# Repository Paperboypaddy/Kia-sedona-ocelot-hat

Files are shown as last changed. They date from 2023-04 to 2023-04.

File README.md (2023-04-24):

# Kia Sedona 2004 Ocelot Hat
The idea of this Ocelot V2 Hat design is to control the stock cruise control system in the car currently as well as adding a K Line Lin Bus tranciever to act like a ELM327 to capture car speed and other stats for openpilot.

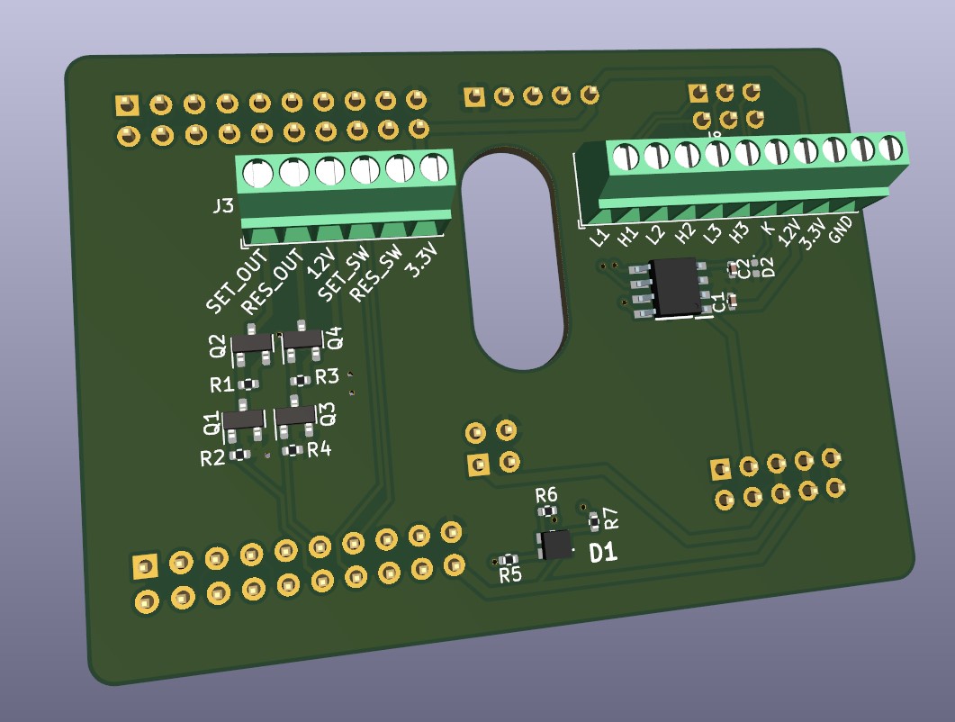
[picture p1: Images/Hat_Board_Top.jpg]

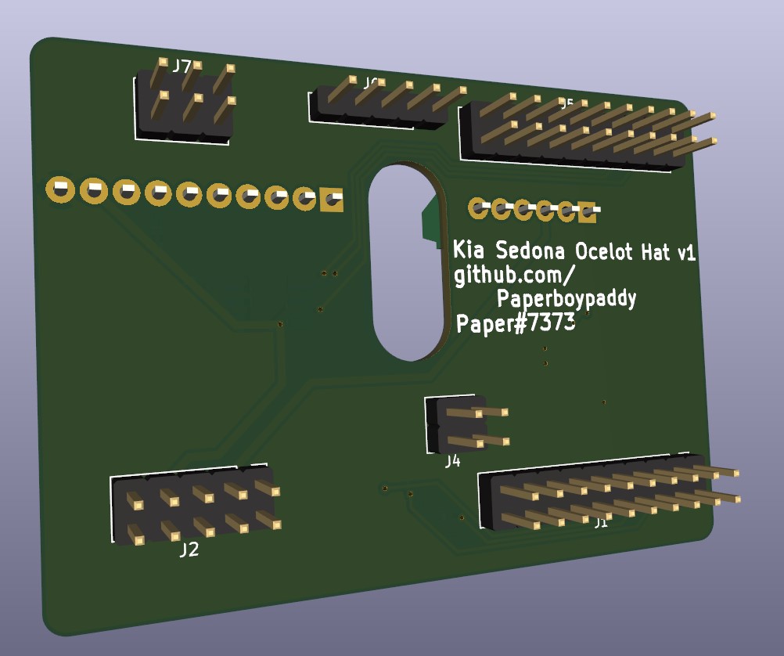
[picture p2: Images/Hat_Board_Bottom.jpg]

Im using a MC33660BEFR2 chip to interface with Lin Bus K-Line over serial USART. USART isconnected to PB10 (TX) and PC5 (RX) on the Ocelot, along with Enable connected to PB1.

As for the cruise control switches and mosfets, my stock cruise control system is using 12v signals for the buttons. The series of mosfets are connected to PC10 (CCSET_INPUT) and PC11 (CCRES_INPUT). And the Stock Switches are connected to 3.3V and PC12 (CCSET_SW) and PD2 (CCRES_SW). 

I've also added a RGB status LED in place where the Black Panda would have had one.
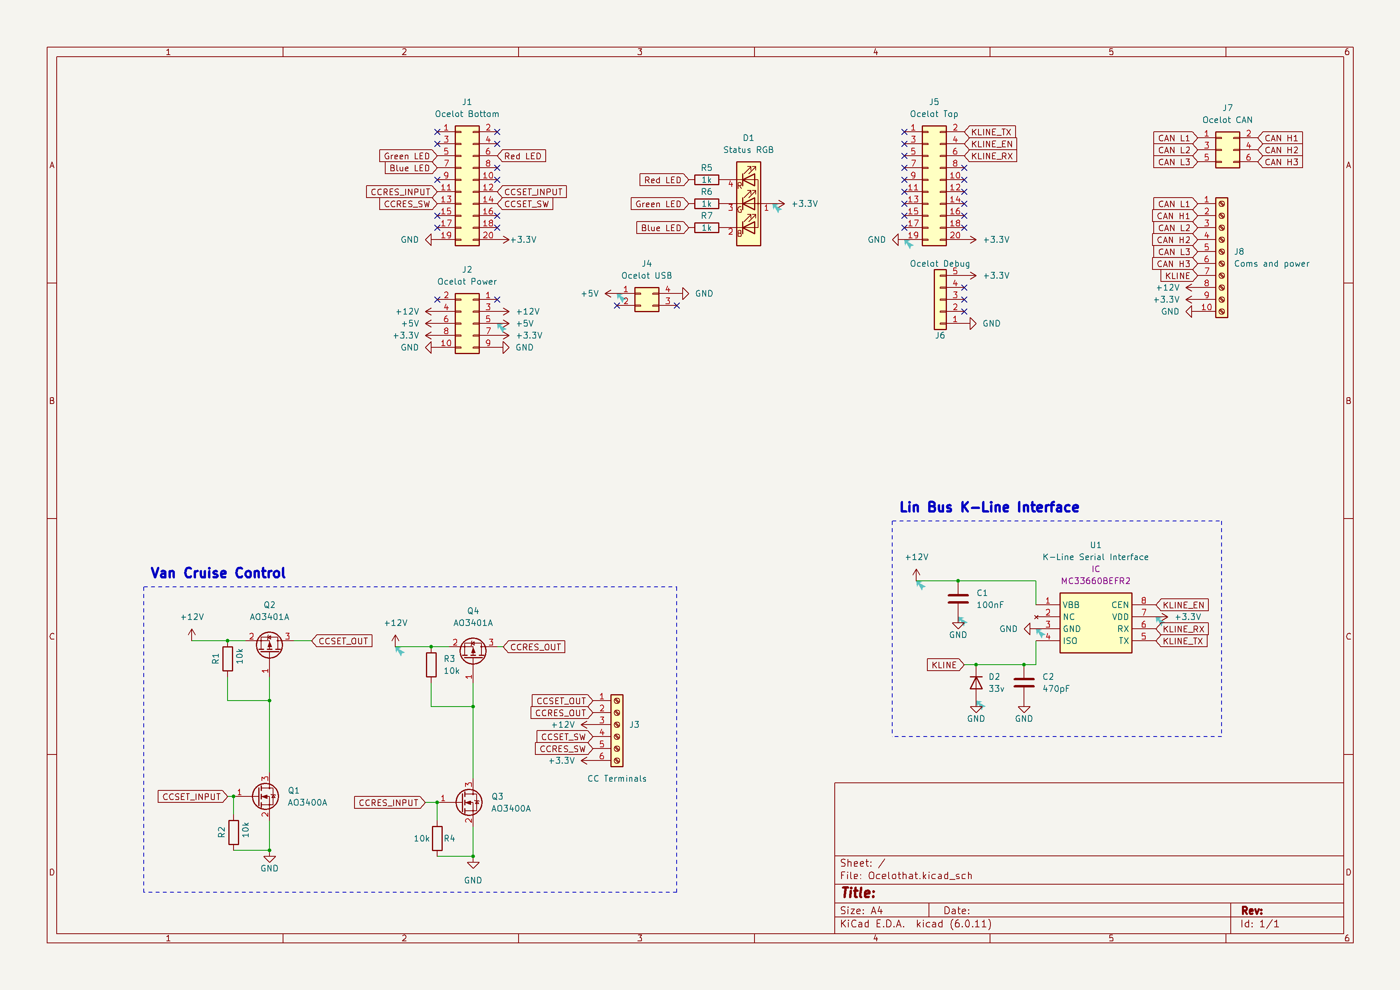
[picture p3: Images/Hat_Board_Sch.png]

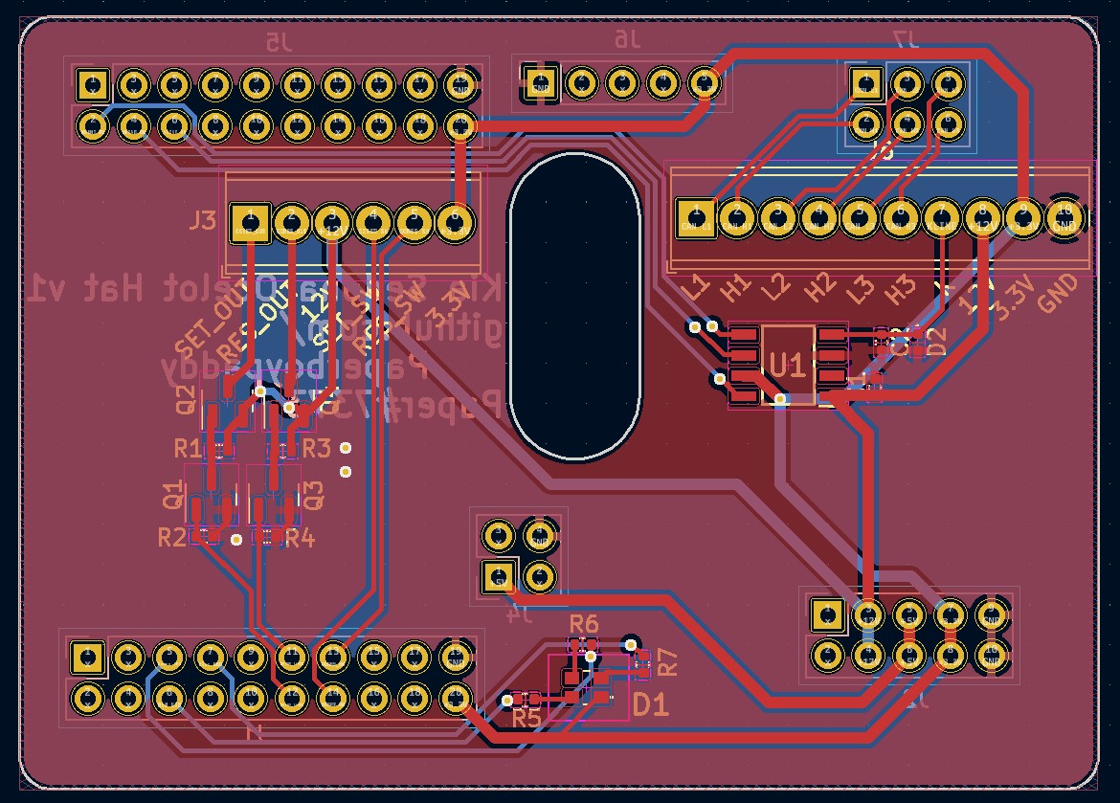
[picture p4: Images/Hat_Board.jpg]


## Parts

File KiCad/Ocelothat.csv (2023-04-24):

Source: | C:\Users\Padraic\Documents\GitHub\Ocelot-Hat\Ocelothat\Ocelothat.kicad_sch
Date: | 4/23/2023 8:42:26 AM
Tool: | Eeschema (6.0.11)
Generator: | C:\Program Files\KiCad\6.0\bin\scripting\plugins/bom_csv_grouped_by_value_with_fp.py
Component Count: | 25
Ref | Qnty | Value | Cmp name | Footprint | Description | Vendor
C1, | 1 | 100nF | C | Capacitor_SMD:C_0402_1005Metric | Unpolarized capacitor
C2, | 1 | 470pF | C | Capacitor_SMD:C_0402_1005Metric | Unpolarized capacitor
D1, | 1 | Status RGB | ASMB-MTB0-0A3A2 | RGB_LED:ASMBLTC20A335 | Tricolor Black Surface LED, Common Anode Pin 1, PLCC-4
D2, | 1 | 33v | D | Diode_SMD:D_0402_1005Metric | Diode
J1, | 1 | Ocelot Bottom | Conn_02x10_Odd_Even | Connector_PinHeader_2.54mm:PinHeader_2x10_P2.54mm_Vertical | Generic connector, double row, 02x10, odd/even pin numbering scheme (row 1 odd numbers, row 2 even numbers), script generated (kicad-library-utils/schlib/autogen/connector/)
J2, | 1 | Ocelot Power | Conn_02x05_Odd_Even | Connector_PinHeader_2.54mm:PinHeader_2x05_P2.54mm_Vertical | Generic connector, double row, 02x05, odd/even pin numbering scheme (row 1 odd numbers, row 2 even numbers), script generated (kicad-library-utils/schlib/autogen/connector/)
J3, | 1 | CC Terminals | Screw_Terminal_01x06 | TerminalBlock_Phoenix:TerminalBlock_Phoenix_MPT-0,5-6-2.54_1x06_P2.54mm_Horizontal | Generic screw terminal, single row, 01x06, script generated (kicad-library-utils/schlib/autogen/connector/)
J4, | 1 | Ocelot USB | Conn_02x02_Counter_Clockwise | Connector_PinHeader_2.54mm:PinHeader_2x02_P2.54mm_Vertical | Generic connector, double row, 02x02, counter clockwise pin numbering scheme (similar to DIP package numbering), script generated (kicad-library-utils/schlib/autogen/connector/)
J5, | 1 | Ocelot Top | Conn_02x10_Odd_Even | Connector_PinHeader_2.54mm:PinHeader_2x10_P2.54mm_Vertical | Generic connector, double row, 02x10, odd/even pin numbering scheme (row 1 odd numbers, row 2 even numbers), script generated (kicad-library-utils/schlib/autogen/connector/)
J6, | 1 | Ocelot Debug | Conn_01x05 | Connector_PinHeader_2.54mm:PinHeader_1x05_P2.54mm_Vertical | Generic connector, single row, 01x05, script generated (kicad-library-utils/schlib/autogen/connector/)
J7, | 1 | Ocelot CAN | Conn_02x03_Odd_Even | Connector_PinHeader_2.54mm:PinHeader_2x03_P2.54mm_Vertical | Generic connector, double row, 02x03, odd/even pin numbering scheme (row 1 odd numbers, row 2 even numbers), script generated (kicad-library-utils/schlib/autogen/connector/)
J8, | 1 | Power Terminals | Screw_Terminal_01x03 | TerminalBlock_Phoenix:TerminalBlock_Phoenix_MPT-0,5-3-2.54_1x03_P2.54mm_Horizontal | Generic screw terminal, single row, 01x03, script generated (kicad-library-utils/schlib/autogen/connector/)
J9, | 1 | Com Terminals | Screw_Terminal_01x08 | TerminalBlock_Phoenix:TerminalBlock_Phoenix_MPT-0,5-8-2.54_1x08_P2.54mm_Horizontal | Generic screw terminal, single row, 01x08, script generated (kicad-library-utils/schlib/autogen/connector/)
Q1, Q3, | 2 | AO3400A | AO3400A | Package_TO_SOT_SMD:SOT-23 | 30V Vds, 5.7A Id, N-Channel MOSFET, SOT-23
Q2, Q4, | 2 | AO3401A | AO3401A | Package_TO_SOT_SMD:SOT-23 | -4.0A Id, -30V Vds, P-Channel MOSFET, SOT-23
R1, R2, R3, R4, | 4 | 10k | R | Resistor_SMD:R_0402_1005Metric | Resistor
R5, R6, R7, | 3 | 1k | R | Resistor_SMD:R_0402_1005Metric | Resistor
U1, | 1 | K-Line Serial Interface | MC33660BEFR2 | LIN_BUS2:SOIC127P600X175-8N | TRANSCEIVER PHYSICAL LAYER ISO

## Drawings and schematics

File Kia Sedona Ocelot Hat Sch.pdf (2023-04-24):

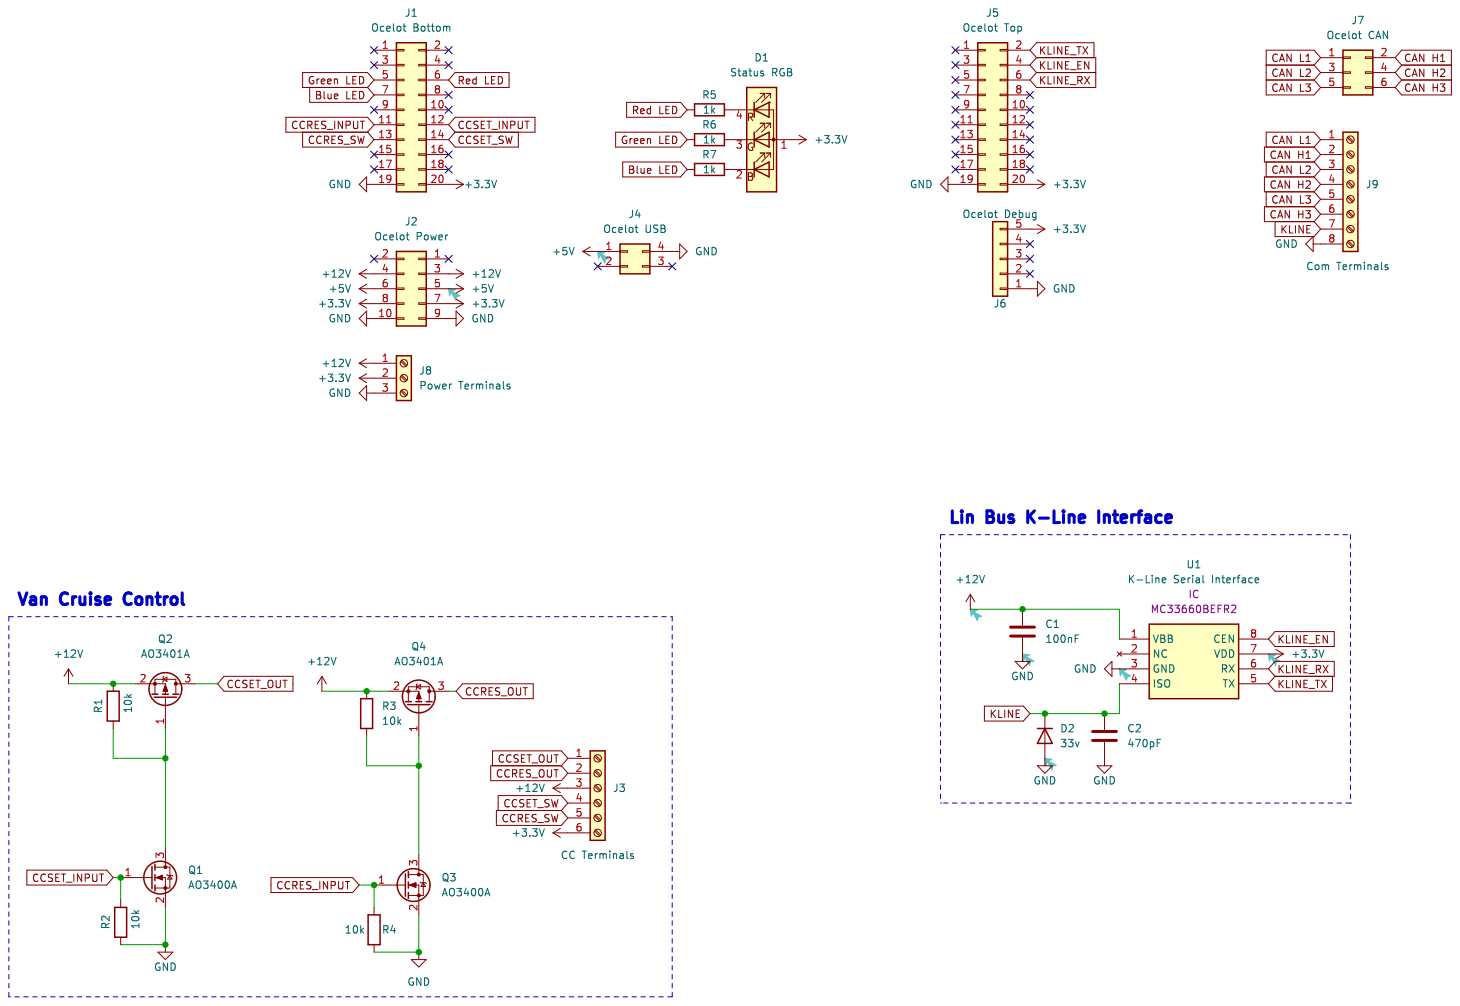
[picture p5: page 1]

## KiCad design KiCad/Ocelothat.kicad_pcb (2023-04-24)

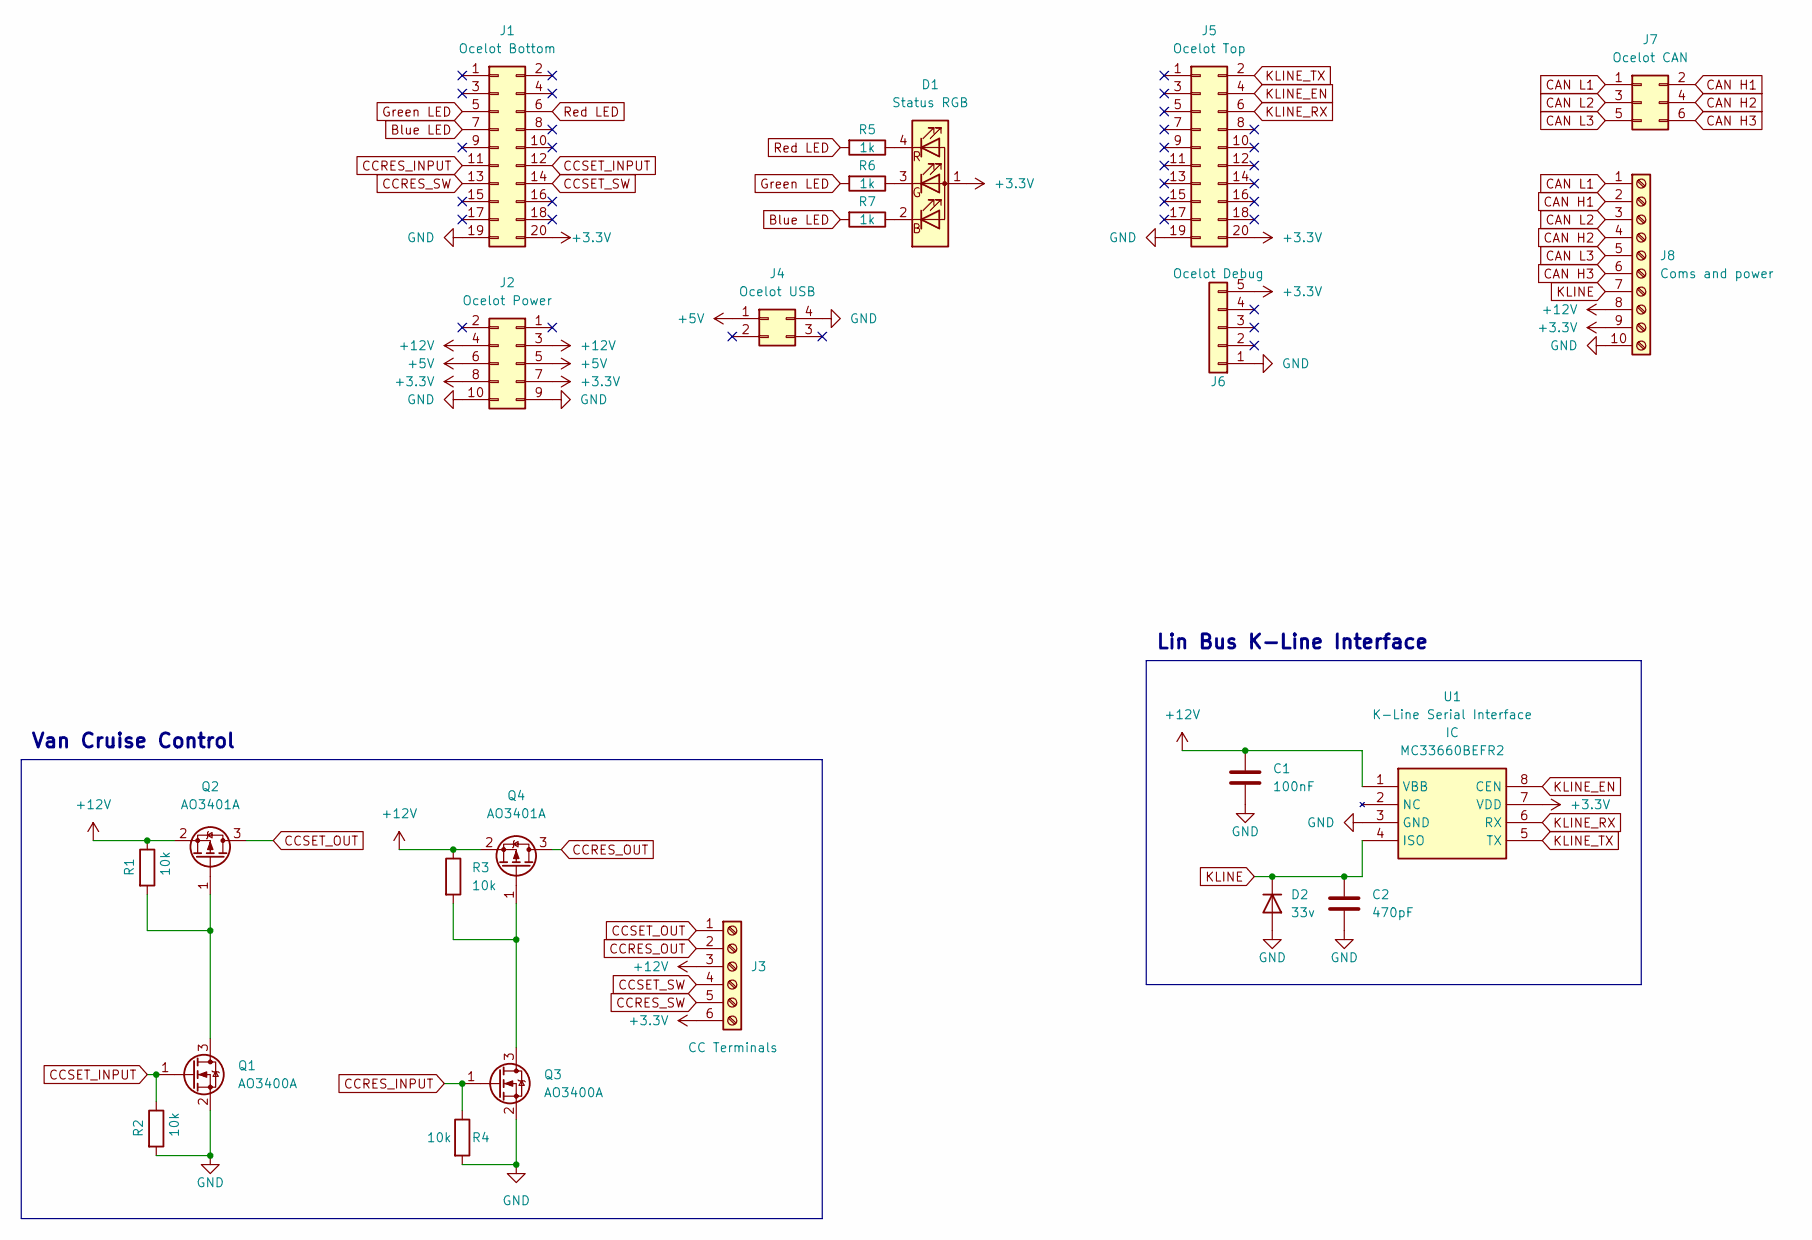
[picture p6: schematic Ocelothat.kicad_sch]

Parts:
C1: 100nF; C_0402_1005Metric
C2: 470pF; C_0402_1005Metric
D1: Status RGB; ASMBLTC20A335
D2: 33v; D_0402_1005Metric
J1: Ocelot Bottom; PinHeader_2x10_P2.54mm_Vertical
J2: Ocelot Power; PinHeader_2x05_P2.54mm_Vertical
J3: CC Terminals; TerminalBlock_Phoenix_MPT-0,5-6-2.54_1x06_P2.54mm_Horizontal
J4: Ocelot USB; PinHeader_2x02_P2.54mm_Vertical
J5: Ocelot Top; PinHeader_2x10_P2.54mm_Vertical
J6: Ocelot Debug; PinHeader_1x05_P2.54mm_Vertical
J7: Ocelot CAN; PinHeader_2x03_P2.54mm_Vertical
J8: Coms and power; TerminalBlock_Phoenix_MPT-0,5-10-2.54_1x10_P2.54mm_Horizont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
Q1, Q3: AO3400A; SOT-23
Q2, Q4: AO3401A; SOT-23
R1, R2, R3, R4: 10k; R_0402_1005Metric
R5, R6, R7: 1k; R_0402_1005Metric
U1: K-Line Serial Interface; SOIC127P600X175-8N; Manufacturer_Part_Number MC33660BEFR2; Mouser Part Number 841-MC33660BEFR2

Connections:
+3.3V: D1.1 (A), J1.20, J2.7, J2.8, J3.6, J5.20, J6.5, J8.9, U1.7 (VDD)
+5V: J2.5, J2.6, J4.1
+12V: C1.1, J2.3, J2.4, J3.3, J8.8, Q2.2 (S), Q4.2 (S), R1.1, R3.1, U1.1 (VBB)
Blue LED: J1.7, R7.2
CAN H1: J7.2, J8.2
CAN H2: J7.4, J8.4
CAN H3: J7.6, J8.6
CAN L1: J7.1, J8.1
CAN L2: J7.3, J8.3
CAN L3: J7.5, J8.5
CCRES_INPUT: J1.11, Q3.1 (G), R4.1
CCRES_OUT: J3.2, Q4.3 (D)
CCRES_SW: J1.13, J3.5
CCSET_INPUT: J1.12, Q1.1 (G), R2.1
CCSET_OUT: J3.1, Q2.3 (D)
CCSET_SW: J1.14, J3.4
GND: C1.2, C2.2, D2.2 (A), J1.19, J2.9, J2.10, J4.4, J5.19, J6.1, J8.10, Q1.2 (S), Q3.2 (S), R2.2, R4.2, U1.3 (GND)
Green LED: J1.5, R6.2
KLINE: C2.1, D2.1 (K), J8.7, U1.4 (ISO)
KLINE_EN: J5.4, U1.8 (CEN)
KLINE_RX: J5.6, U1.6 (RX)
KLINE_TX: J5.2, U1.5 (TX)
unnamed: D1.2 (BK), R7.1
unnamed: D1.3 (GK), R6.1
unnamed: D1.4 (RK), R5.1
unnamed: Q1.3 (D), Q2.1 (G), R1.2
unnamed: Q3.3 (D), Q4.1 (G), R3.2
Red LED: J1.6, R5.2

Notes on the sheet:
Van Cruise Control
Lin Bus K-Line Interface

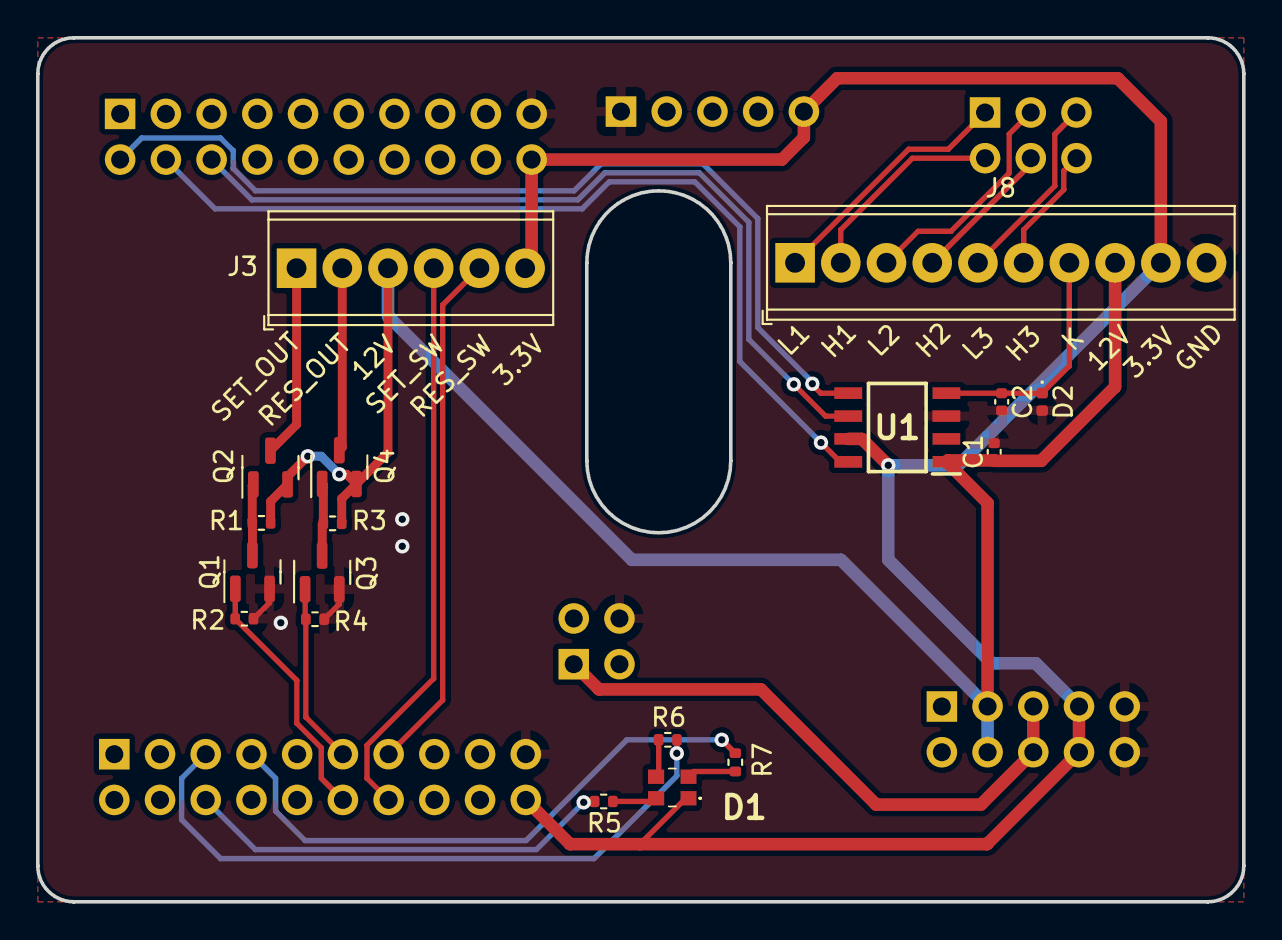
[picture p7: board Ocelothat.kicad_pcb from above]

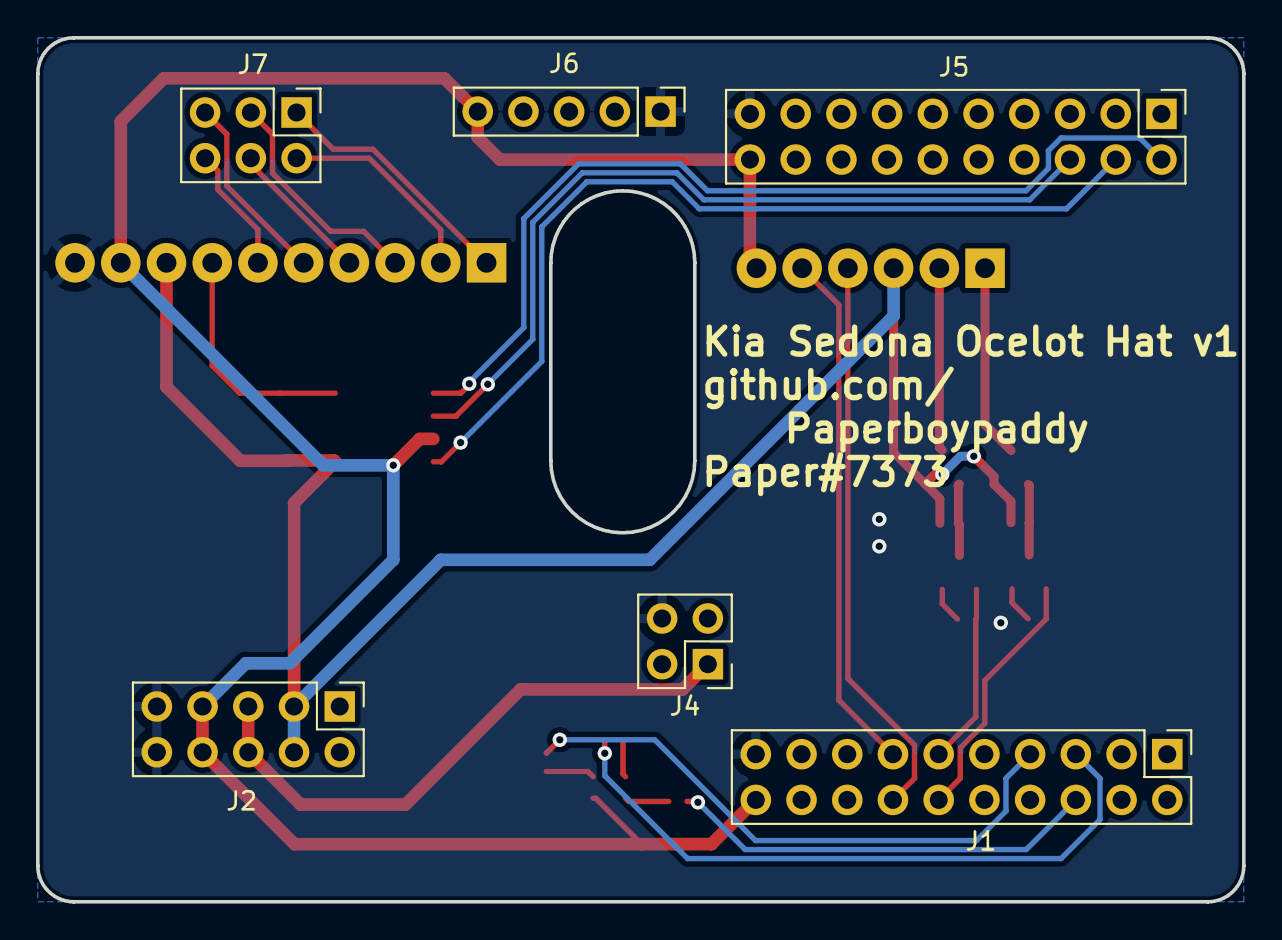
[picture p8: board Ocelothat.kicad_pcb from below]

Board: 2 copper layers, 67.0 x 48.0 mm, 24 parts (6 on the bottom side), 28 nets.

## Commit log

2023-04-24 Uploading KiCad Design
    [Ocelot Hat PCB.dxf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]
2023-04-24 Changed Folder name to KiCad and added images
    [Ocelot Hat PCB.dxf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]
2023-04-24 Added board Sch image
